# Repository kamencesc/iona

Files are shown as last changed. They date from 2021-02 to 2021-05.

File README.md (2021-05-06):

# Tested

The code was tested on a prototype board by Stefano Minozzi (cyllboy).

Freel free to contact for questions about code and board.

!! ALERT: It seems that has some issues with Neogeo CD Gamepad, DB15 pin 8 is connected to RAW causing not working correctly. (15/02/2021) !!

# IONA - JVS IO Board by Arduino Pro Micro

Original code by [Takashi Toyoshima](https://github.com/toyoshim).

This program makes an Arduino Pro Micro (With atmega 32u4) work as a JVS IO Board that allows you to connect a legacy JAMMA joystick to a JVS based arcade system, such as NAOMI.

Since now underlying [jvsio](https://github.com/toyoshim/jvsio) library supports several boards and devices, you would be able to run this on other boards with minimal hacks.

Also there is [another example](https://github.com/toyoshim/iona-js) to run iona compatible functionalities without the Arduino firmware.

The USB-HID part for USB Joystick needs [Joystick Library by Matthew Heironimus](https://github.com/MHeironimus/ArduinoJoystickLibrary) and there is how to install it [Installing Additional Arduino Libraries](https://www.arduino.cc/en/guide/libraries).

## Schematic

This program makes an Arduino Pro Micro work as a JVS IO Board that allows youto connect a legacy AES compatible joystick gamepad (included Button 5 and 6 for customomized arcade sticks.

Since now underlying [jvsio](https://github.com/toyoshim/jvsio) library supports several boards and devices, you would be able to run this on other boards with minimal hacks.

Also there is [another example](https://github.com/toyoshim/iona-js) to run iona compatible functionalities without the Arduino firmware.

Resistor (R1) and capacitor (C1) are 100Ohm and 100nF 0603 SMD.

The PCB is based in this DB15 AES compatible pinout:
```
.----------------------------------------------------------------.
\ 1:GND   2:B6    3:CDT   4:B4    5:B2    6:RGH   7:DWN   8:+5V  /
 \                                                              /
  \  9:NC   10:B5   11:STR    12:B3   13:B1   14:LFT    15:UP  /
    `---------------------------------------------------------´
```
The Board  has a jumper, if it's shorted then it works as a USB Stick for a computer, using the micro USB of Arduino., else it works aas a JVS for the naomi using the USB B connector.

In JVS mode, the Naomi's USB doesn't give power to the board, use the micro USB connector or the power jumpers on the board (See legend on the back side of the PCB). You can get 5V from CN7 on the Naomi Board.
```
 _________________
| 5V  5V  GND GND |   CN7
 ¯¯¯¯¯¯¯¯¯¯¯¯¯¯¯¯¯
```
!! Be careful with your Pro Micro's voltage config, jumper J1 needs to be set at 5V !!
## Board (PCB)

The GND pins from the arduino are marked in white, and there's an indication of USB and J1 position.

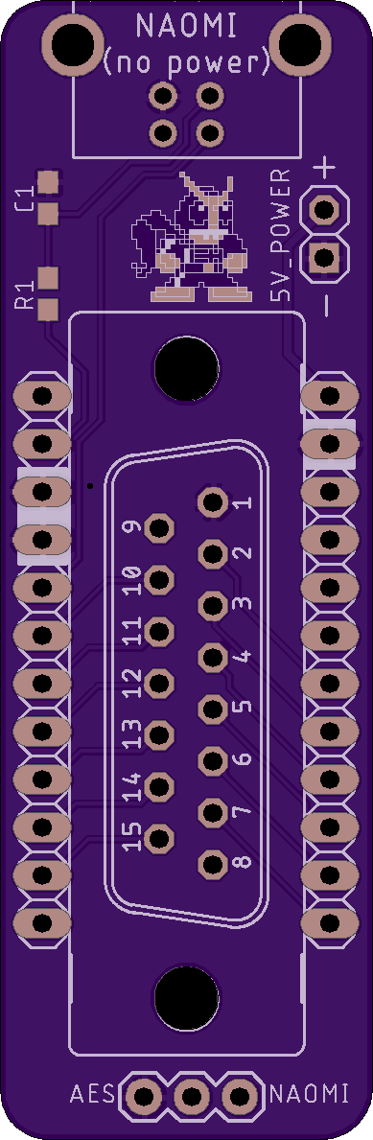
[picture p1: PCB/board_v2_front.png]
PCB_front
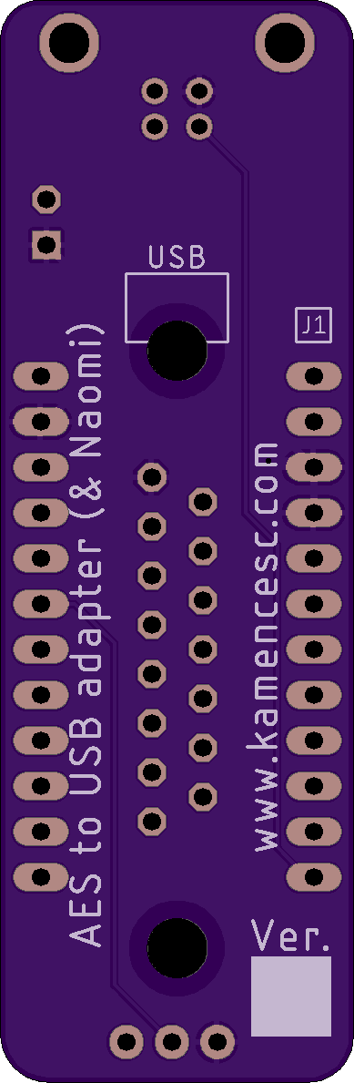
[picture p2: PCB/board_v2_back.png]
PCB_back
 

Be sure that you mount the pinheader on the component side of the arduino:

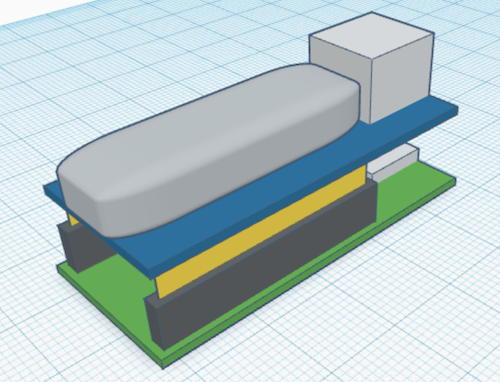
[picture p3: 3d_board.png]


## !! Use an Arduino Pro Micro with micro USB connector, the mini USB version is a little wider) !! ##

ARDUINO

And, the pins go up, the PCB is used like a regular Shield.

Note: JVS uses the USB connector, but it isn't the real USB at all.
The protocol is completely different, and it does not provide the 5V power.

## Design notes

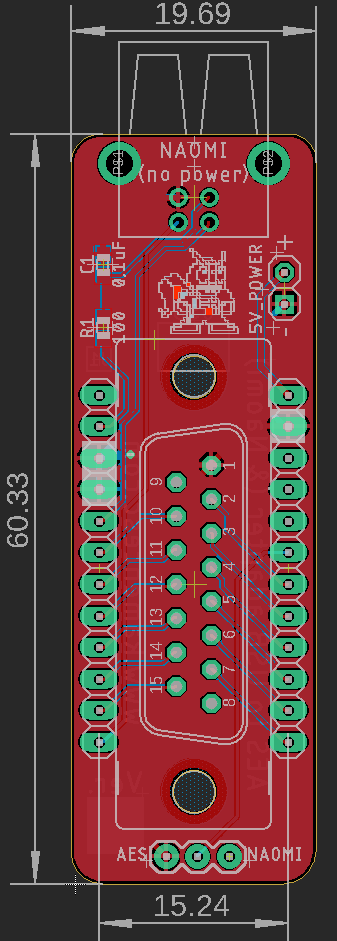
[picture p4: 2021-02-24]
PCB/board_v2.png

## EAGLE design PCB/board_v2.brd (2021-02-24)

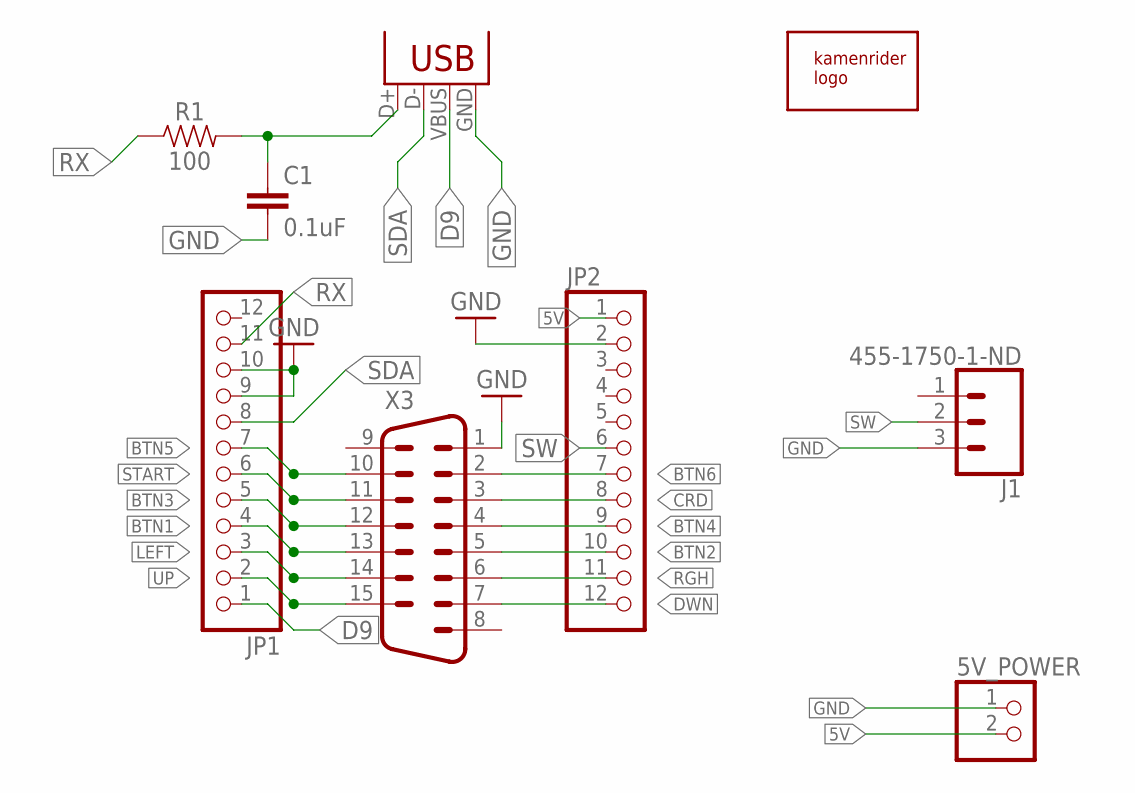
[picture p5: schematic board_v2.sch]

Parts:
5V_POWER: PINHD-1X02_2.54-S; 1X02-S
C1: 0.1uF; 0603
J1: 455-1750-1-ND; 1X03
JP1, JP2: PINHD-1X12; 1X12
R1: 100; 0603
U$1: KAMENRIDER_LOGOV2_COLOR_OPAC; 10_6_V2
X2: USB-B-H
X3: M15V

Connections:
5V: 5V_POWER.2, JP2.1
BTN1: JP1.4, X3.13
BTN2: JP2.10, X3.5
BTN3: JP1.5, X3.12
BTN4: JP2.9, X3.4
BTN5: JP1.7, X3.10
BTN6: JP2.7, X3.2
CRD: JP2.8, X3.3
D9: JP1.1, X2.VBUS
DWN: JP2.12, X3.7
GND: 5V_POWER.1, C1.2, J1.3, JP1.9, JP1.10, JP2.2, X2.GND, X3.1
LEFT: JP1.3, X3.14
RGH: JP2.11, X3.6
RX: JP1.11, R1.1
RX_R: C1.1, R1.2, X2.D+
SDA: JP1.8, X2.D-
START: JP1.6, X3.11
SW: J1.2, JP2.6
UP: JP1.2, X3.15

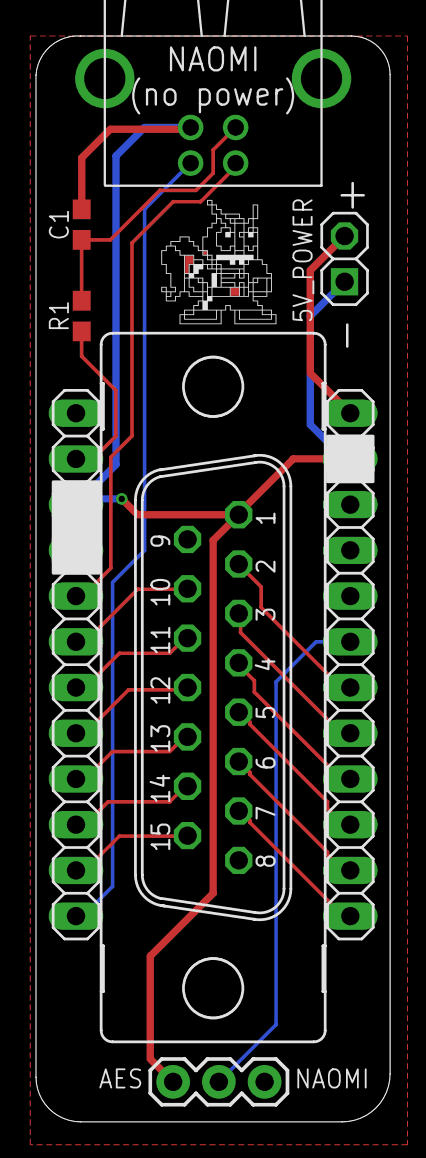
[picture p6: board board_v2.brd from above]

Board: 2 copper layers, 19.7 x 60.3 mm, 9 parts (0 on the bottom side), 19 nets.

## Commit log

2021-02-24 Add files via upload
    New PCB
    [Placa V1.brd, Placa V1.sch]
2021-02-24 Rename Placa V1.brd to board_v2.brd
    [board_v2.brd]
2021-02-24 Rename Placa V1.sch to board_v2.sch
    [board_v2.sch]
2021-04-09 Update README.md
    Info about pins on the Arduino.
2021-05-06 Add files via upload
    3d board about how to assemble

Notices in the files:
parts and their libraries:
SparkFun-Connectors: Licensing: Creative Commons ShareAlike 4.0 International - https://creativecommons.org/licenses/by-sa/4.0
